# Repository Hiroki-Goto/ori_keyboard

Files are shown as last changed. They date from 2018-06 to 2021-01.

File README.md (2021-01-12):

# My best original keyboard
This repository is development one of original keyboard
for me (The name is undecided yet).

Software is developed by [qmk firmware](https://github.com/qmk/qmk_firmware).

## We can't find avr-gcc command
After qmk setupping, if you use mac OS, avr-gcc may be not found.
Please refer [this WEB site](https://bytes.usc.edu/ee109/macos-64-bit-toolchain/).

## Constitution keyboard
These module are connected with Pro micro as figure.
- 2 I/O expanders (scanning key matrix each other)
- Displaying current layer on OLED module
- Pointing device (uncertain)
    - Track ball module 
    - joystick 

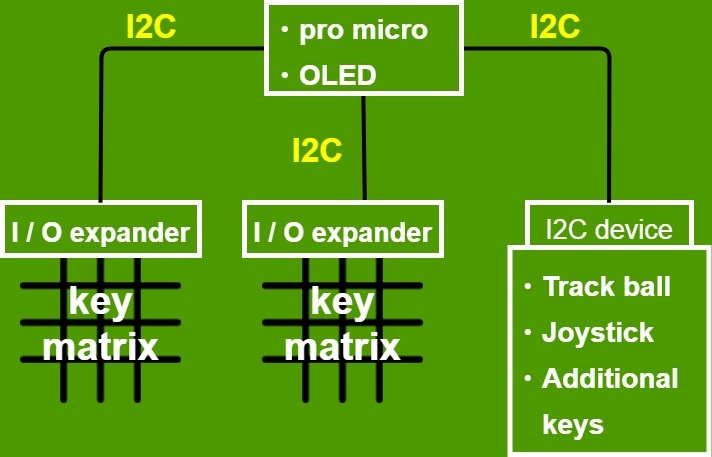
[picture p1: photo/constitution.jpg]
Constitution


There may be others.....

## Development record
- [software](https://github.com/Hiroki-Goto/qmk_firmware/tree/hiro_test)  

- [Development record](https://github.com/Hiroki-Goto/ori_keyboard/issues)

# Licence

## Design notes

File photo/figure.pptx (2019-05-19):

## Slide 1

LEFT

GND
RX
TX
VCC

RIGHT

VCC
RX
TX
GND

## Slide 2

Master

GND
SDA
SCL
VCC

Slave

VCC
SCL
SDA
GND

USB
Cable

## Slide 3

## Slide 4

I2C

Pro
Micro

GPIO

Key
Matrix

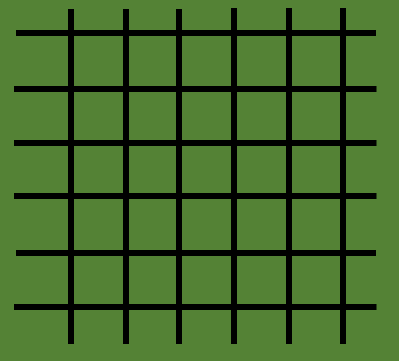
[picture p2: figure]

I2C

Pro
Micro

Key
Matrix

GPIO

OLED

SERIAL

Track
Ball

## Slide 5

Main module

Pro micro and OLED

I2C

I2C

I2C

IO expander

Key matrix

IO expander

Key matrix

Track ball
module

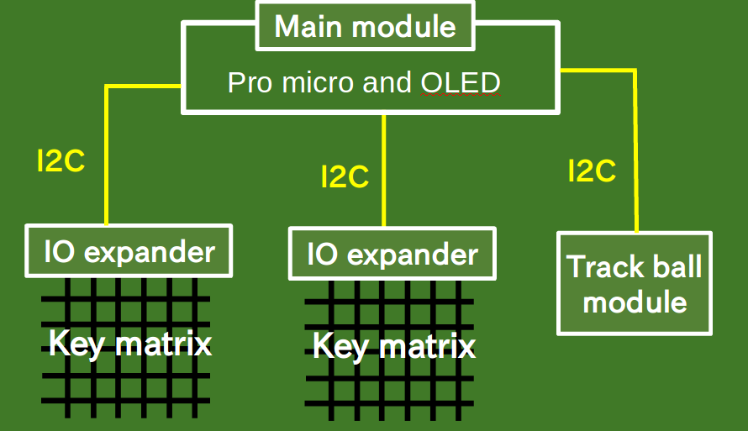
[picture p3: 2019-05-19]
photo/constitution.png

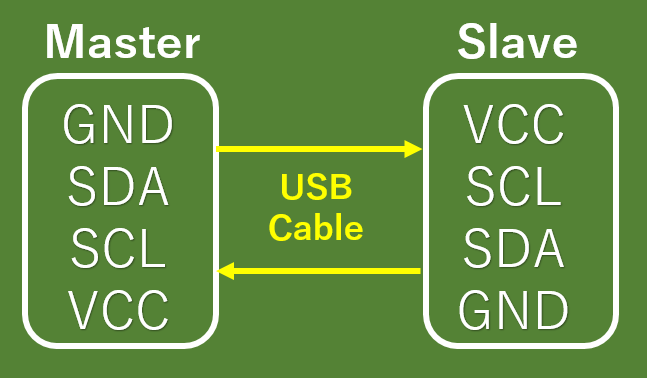
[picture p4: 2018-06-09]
photo/i2c_connect.PNG

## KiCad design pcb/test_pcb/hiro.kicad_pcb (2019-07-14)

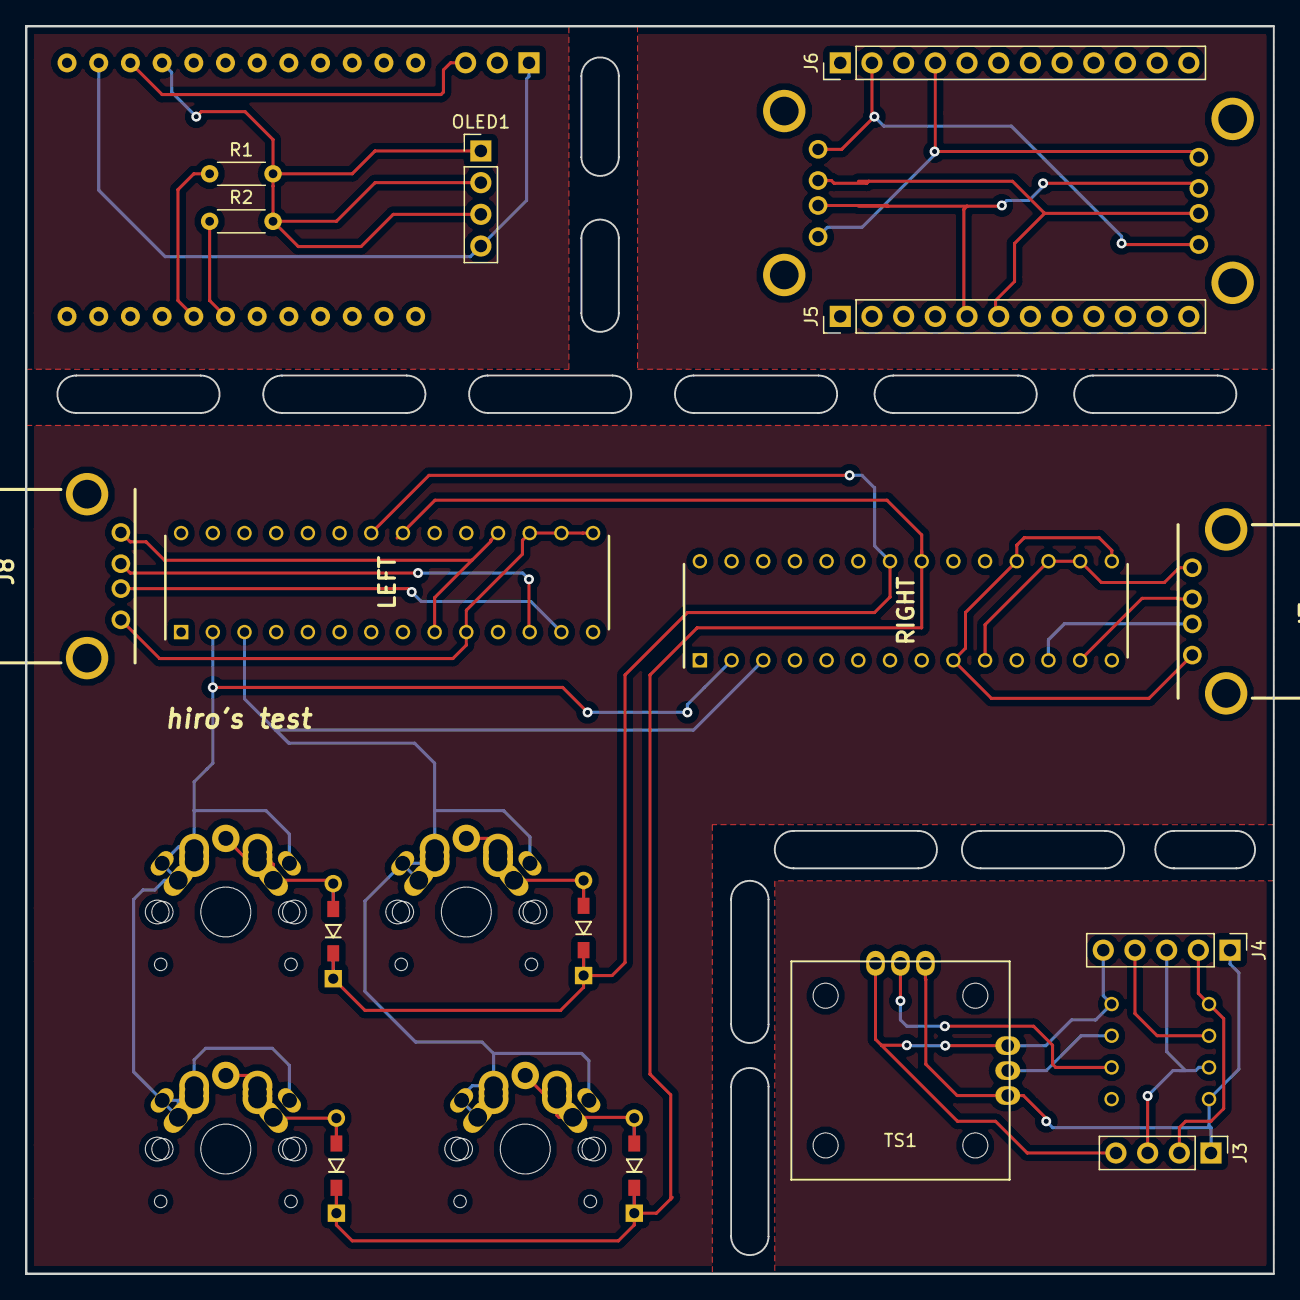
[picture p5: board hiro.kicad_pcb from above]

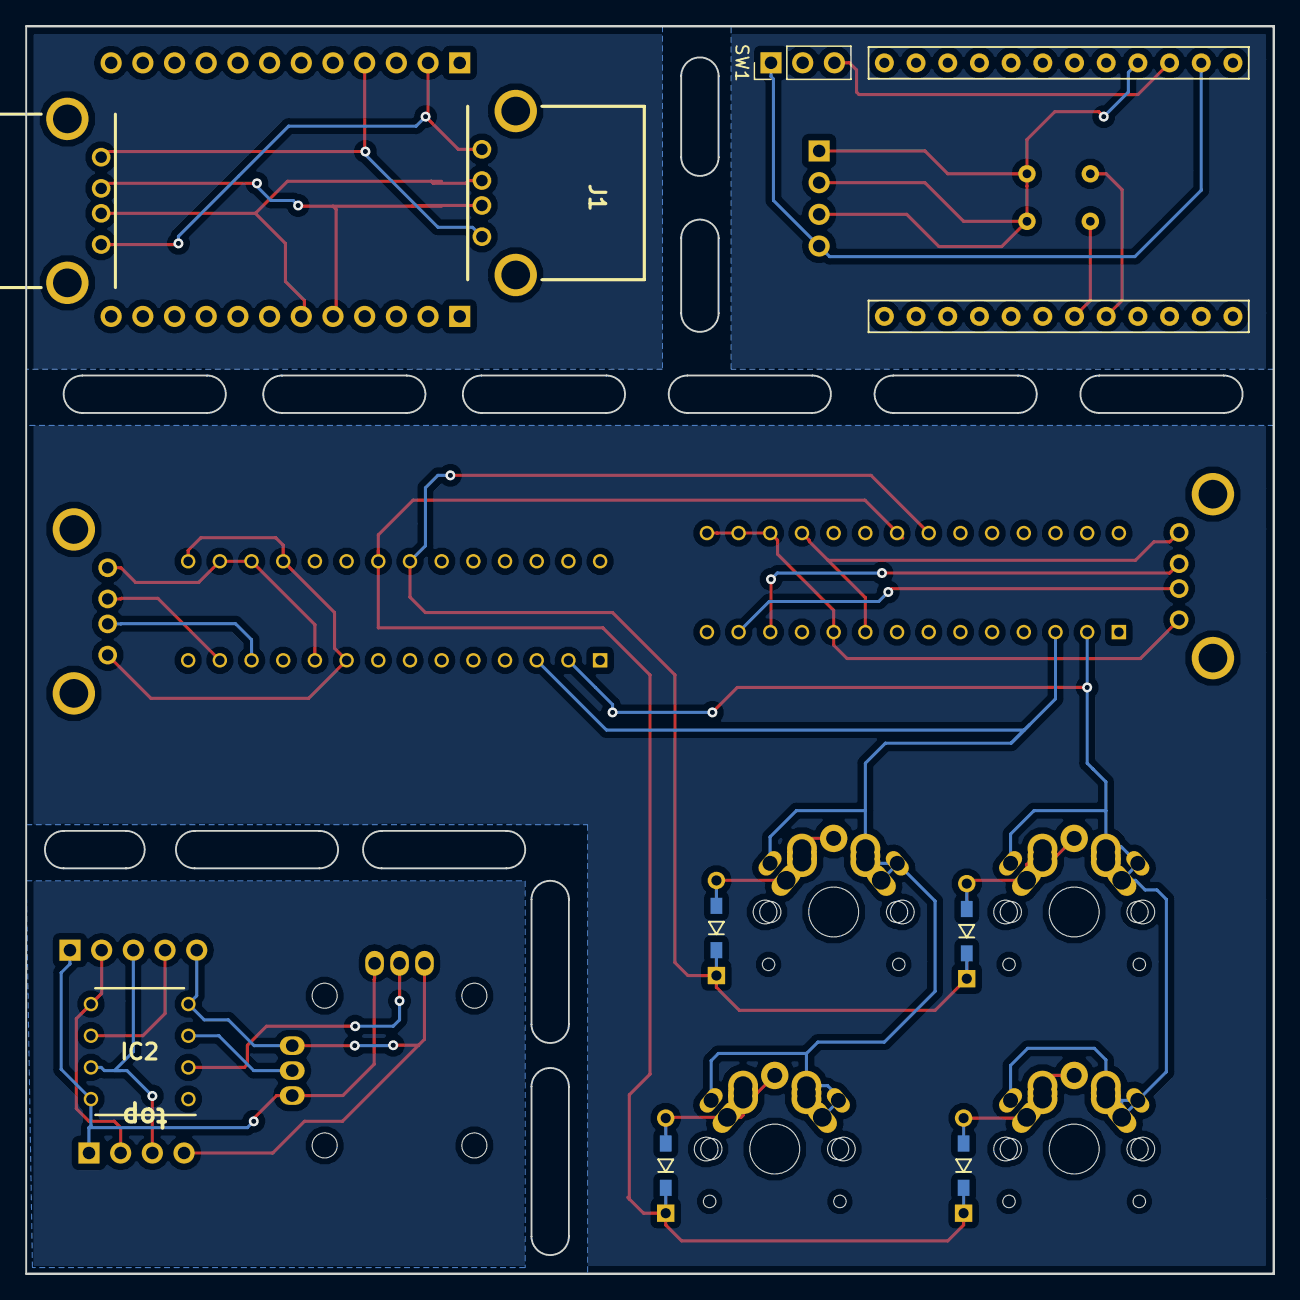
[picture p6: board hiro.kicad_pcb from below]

Board: 2 copper layers, 100.0 x 100.0 mm, 25 parts (4 on the bottom side), 30 nets.

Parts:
D1, D2, D3, D4: 1N4148; diode
IC1: DEV-12587; no_moge_micle
IC2: ATTINY85-20PU; DIP781W56P254L950H533Q8N
J1, J2, J7, J8: 614004190021; USB-2.0-TYPE-A
J3: Conn_01x04; PinHeader_1x04_P2.54mm_Vertical
J4: Conn_01x05; PinHeader_1x05_P2.54mm_Vertical
J5, J6: Conn_01x12; PinHeader_1x12_P2.54mm_Vertical
LEFT: MCP23017-E_SP; DIP794W56P254L3486H508Q28N
OLED1: Conn_01x04; PinHeader_1x04_P2.54mm_Vertical
R1, R2: R; R_Axial_DIN0204_L3.6mm_D1.6mm_P5.08mm_Horizontal
RIGHT: MCP23017-E_SP; DIP794W56P254L3486H508Q28N
SW1: SW_DIP_x02; PinHeader_1x03_P2.54mm_Vertical
SW2, SW3, SW4: SW_PUSH; key_switch_1u
SW5: SW_PUSH; key_switch_15u
TS1: JT8P-3.2T-B10K-1-16Y

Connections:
0: J7.4, J8.4, LEFT.10, LEFT.15, LEFT.16, LEFT.17, RIGHT.10, RIGHT.16, RIGHT.17
5V: IC1.21, OLED1.1, OLED1.2, OLED1.3, R1.2, R2.2
+5V: J7.1, J8.1, LEFT.9, LEFT.18, RIGHT.9, RIGHT.15, RIGHT.18
/tiny/GND: IC2.4, J3.4, J4.5, TS1.3
/tiny/MISO: IC2.6, J4.4
/tiny/TINY_5: IC2.5, J3.2, J4.2
/tiny/TINY_7: IC2.7, J3.3, J4.3
/tiny/VCC: IC2.8, J3.1, J4.1, TS1.1
/tiny/x: IC2.2, TS1.2
/tiny/y: IC2.3, TS1.4
B_5V: J1.1, J2.1, J6.4
B_GND: J1.4, J2.4, J6.2
B_SCL: J1.3, J2.3, J5.6
B_SDA: J1.2, J2.2, J5.5
GND: IC1.23, OLED1.4, SW1.1, SW1.2
unnamed: D1.2, SW2.2
unnamed: D2.2, SW3.2
unnamed: D3.2, SW4.2
unnamed: D4.2, SW5.2
unnamed: IC1.5, R1.1
unnamed: IC1.6, R2.1
unnamed: J7.2, RIGHT.12
unnamed: J7.3, RIGHT.13
unnamed: J8.2, LEFT.12
unnamed: J8.3, LEFT.13
RST: IC1.22, SW1.3
col0: D1.1, D3.1, LEFT.22, RIGHT.22
col1: D2.1, D4.1, LEFT.21, RIGHT.21
row0: LEFT.2, RIGHT.2, SW2.1, SW3.1
row1: LEFT.3, RIGHT.3, SW4.1, SW5.1

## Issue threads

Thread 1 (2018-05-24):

pro micro 同士でシリアル通信

Hiroki-Goto, 2018-05-24:
左右分離になっているため、シリアル通信ori2c通信を行う必要がある
現状はシリアル通信を行う予定

- [x] 1byteで送るメッセージを決める（マウス移動量も含む）

- [x] [USBコネクタ](http://akizukidenshi.com/catalog/g/gK-07429/)で通信できるか確認

Hiroki-Goto, 2018-05-26:
USBコネクタでもいけた
配線はD+とD-は左右で異なるピンに接続する必要がある

Hiroki-Goto, 2018-05-26:
USB2.0コネクタで通信しているときの問題として入力のラグなど問題がある
解決策策として以下のものを試してみる
- USB3.0に変更してみる

- 左右の通信速度を変更してみる

- プログラム中のdilayを消す

-

Hiroki-Goto, 2018-05-27:
配線の問題だった模様

Closed 2018-05-27.

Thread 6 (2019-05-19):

複数のIOエキスパンダーに対応

Hiroki-Goto, 2019-05-19:
一つのIOエキスパンダーで１ｘ２のスキャンが可能になったので、もうひとつ追加する

Hiroki-Goto, 2019-05-26:
複数個のエキスパンダーに対応できた

Hiroki-Goto, 2019-06-29:
行増やすと問題が起きたので再オープン

Hiroki-Goto, 2019-06-29:
毎回コピるのが面倒なので、[qmk](https://github.com/Hiroki-Goto/qmk_firmware)側でアップ
ergodoneの中をいじればいけるかもしれない

Hiroki-Goto, 2019-06-29:
最新版で対応したので閉じる

Closed 2019-06-29.

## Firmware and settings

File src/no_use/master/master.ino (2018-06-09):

#include <Wire.h>
#include <Keyboard.h>

#include <Mouse.h>


#include "key_master.h"
#include "param.h"
//#include "keycode.h"
#include "OLED.h"

KeyMaster keyMaster(0);
OLED oled(0);
keyboradState keyboard_state_t;

void setup() {
    keyboard_state_t.current_layer = _DEFAULT;
    keyboard_state_t.num_lock = false;
    keyboard_state_t.caps_lock = false;
    keyboard_state_t.scr_lock = false;

    Serial.begin(9600);
    Serial1.begin(9600);
    Keyboard.begin();
    Wire.begin();
}

void loop() {
    keyMaster.scanMatrix(&keyboard_state_t);
    oled.display(&keyboard_state_t);
    //delay(10);
}

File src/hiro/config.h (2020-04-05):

/*
Copyright 2019 Hiroki-Goto

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
You should have received a copy of the GNU General Public License
along with this program.  If not, see <http://www.gnu.org/licenses/>.
*/

#ifndef CONFIG_H
#define CONFIG_H

#pragma once

#include "config_common.h"

/* USB Device descriptor parameter */
#define VENDOR_ID       0xFEED
#define PRODUCT_ID      0x0000
#define DEVICE_VER      0x0001
#define MANUFACTURER    Hiroki-Goto
#define PRODUCT         hiro
#define DESCRIPTION     A custom keyboard

/* key matrix size */
#define MATRIX_ROWS 2	//port B
#define MATRIX_COLS 7	//left port A + rithgt port A

// this is right colnums number
#define MATRIX_COLS_SPLIT 1

/*
 * Keyboard Matrix Assignments
 *
 * Change this to how you wired your keyboard
 * COLS: AVR pins used for columns, left to right
 * ROWS: AVR pins used for rows, top to bottom
 * DIODE_DIRECTION: COL2ROW = COL = Anode (+), ROW = Cathode (-, marked on diode)
 *                  ROW2COL = ROW = Anode (+), COL = Cathode (-, marked on diode)
 *
*/
//#define ROW_EXPANDED {true}
#define MATRIX_ROW_PINS { }
//#define COL_EXPANDED {true, true, true}
#define MATRIX_COL_PINS { }
#define UNUSED_PINS

/* COL2ROW, ROW2COL*/
#define DIODE_DIRECTION COL2ROW

/*
 * Split Keyboard specific options, make sure you have 'SPLIT_KEYBOARD = yes' in your rules.mk, and define SOFT_SERIAL_PIN.
 */
//#define SOFT_SERIAL_PIN D0 // or D1, D2, D3, E6

// #define BACKLIGHT_PIN B7
// #define BACKLIGHT_BREATHING
// #define BACKLIGHT_LEVELS 3

// #define RGB_DI_PIN E2
// #ifdef RGB_DI_PIN
//   #define RGBLED_NUM 16
//   #define RGBLIGHT_HUE_STEP 8
//   #define RGBLIGHT_SAT_STEP 8
//   #define RGBLIGHT_VAL_STEP 8
//   #define RGBLIGHT_LIMIT_VAL 255 /* The maximum brightness level */
//   #define RGBLIGHT_SLEEP  /* If defined, the RGB lighting will be switched off when the host goes to sleep */
// /*== all animations enable ==*/
//   #define RGBLIGHT_ANIMATIONS
// /*== or choose animations ==*/
//   #define RGBLIGHT_EFFECT_BREATHING
//   #define RGBLIGHT_EFFECT_RAINBOW_MOOD
//   #define RGBLIGHT_EFFECT_RAINBOW_SWIRL
//   #define RGBLIGHT_EFFECT_SNAKE
//   #define RGBLIGHT_EFFECT_KNIGHT
//   #define RGBLIGHT_EFFECT_CHRISTMAS
//   #define RGBLIGHT_EFFECT_STATIC_GRADIENT
//   #define RGBLIGHT_EFFECT_RGB_TEST
//   #define RGBLIGHT_EFFECT_ALTERNATING
// /*== customize breathing effect ==*/
//   /*==== (DEFAULT) use fixed table instead of exp() and sin() ====*/
//   #define RGBLIGHT_BREATHE_TABLE_SIZE 256      // 256(default) or 128 or 64
//   /*==== use exp() and sin() ====*/
//   #define RGBLIGHT_EFFECT_BREATHE_CENTER 1.85  // 1 to 2.7
//   #define RGBLIGHT_EFFECT_BREATHE_MAX    255   // 0 to 255
// #endif

/* Debounce reduces chatter (unintended double-presses) - set 0 if debouncing is not needed */
#define DEBOUNCING_DELAY 20

/* define if matrix has ghost (lacks anti-ghosting diodes) */
//#define MATRIX_HAS_GHOST

/* number of backlight levels */

/* Mechanical locking support. Use KC_LCAP, KC_LNUM or KC_LSCR instead in keymap */
#define LOCKING_SUPPORT_ENABLE
/* Locking resynchronize hack */
#define LOCKING_RESYNC_ENABLE

/* If defined, GRAVE_ESC will always act as ESC when CTRL is held.
 * This is userful for the Windows task manager shortcut (ctrl+shift+esc).
 */
// #define GRAVE_ESC_CTRL_OVERRIDE

/*
 * Force NKRO
 *
 * Force NKRO (nKey Rollover) to be enabled by default, regardless of the saved
 * state in the bootmagic EEPROM settings. (Note that NKRO must be enabled in the
 * makefile for this to work.)
 *
 * If forced on, NKRO can be disabled via magic key (default = LShift+RShift+N)
 * until the next keyboard reset.
 *
 * NKRO may prevent your keystrokes from being detected in the BIOS, but it is
 * fully operational during normal computer usage.
 *
 * For a less heavy-handed approach, enable NKRO via magic key (LShift+RShift+N)
 * or via bootmagic (hold SPACE+N while plugging in the keyboard). Once set by
 * bootmagic, NKRO mode will always be enabled until it is toggled again during a
 * power-up.
 *
 */
//#define FORCE_NKRO

/*
 * Magic Key Options
 *
 * Magic keys are hotkey commands that allow control over firmware functions of
 * the keyboard. They are best used in combination with the HID Listen program,
 * found here: https://www.pjrc.com/teensy/hid_listen.html
 *
 * The options below allow the magic key functionality to be changed. This is
 * useful if your keyboard/keypad is missing keys and you want magic key support.
 *
 */

/* key combination for magic key command */
/* defined by default; to change, uncomment and set to the combination you want */
// #define IS_COMMAND() (get_mods() == (MOD_BIT(KC_LSHIFT) | MOD_BIT(KC_RSHIFT)))

/* control how magic key switches layers */
//#define MAGIC_KEY_SWITCH_LAYER_WITH_FKEYS  true
//#define MAGIC_KEY_SWITCH_LAYER_WITH_NKEYS  true
//#define MAGIC_KEY_SWITCH_LAYER_WITH_CUSTOM false
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

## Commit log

2018-05-23 OLEDに表示する機能の追加
2018-05-26 シリアル通信の実装
2018-06-09 i2cでも通信ができた
2018-06-09 レイヤー機能のバグ修正
2018-06-09 初期化のバグ修正
2019-05-18 qmkに対応中
2019-05-26 複数に対応
2019-07-14 change readme figure
    [expander.sch, hiro.kicad_pcb, hiro.sch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]
2020-03-15 ソース上げ
2020-04-05 行の開始位置などがおかしい問題の修正
2021-01-12 qmkのビルドできない問題を記載

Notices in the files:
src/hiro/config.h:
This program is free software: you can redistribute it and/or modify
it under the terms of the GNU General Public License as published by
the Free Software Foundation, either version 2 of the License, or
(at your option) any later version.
